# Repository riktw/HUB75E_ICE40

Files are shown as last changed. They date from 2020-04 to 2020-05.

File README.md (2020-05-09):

# HUB75E_ICE40
SpinalHDL code to drive a 64*64 pixel HUB75E module with an ICE40

This code is used to drive a HUB75E dislay, fast enough to display animated gifs:


This project uses SpinalHDL, see installation notes here: https://spinalhdl.github.io/SpinalDoc-RTD/SpinalHDL/Getting%20Started/index.html

To build, yosys and nextpnr are used, see installation notes here: http://www.clifford.at/icestorm/

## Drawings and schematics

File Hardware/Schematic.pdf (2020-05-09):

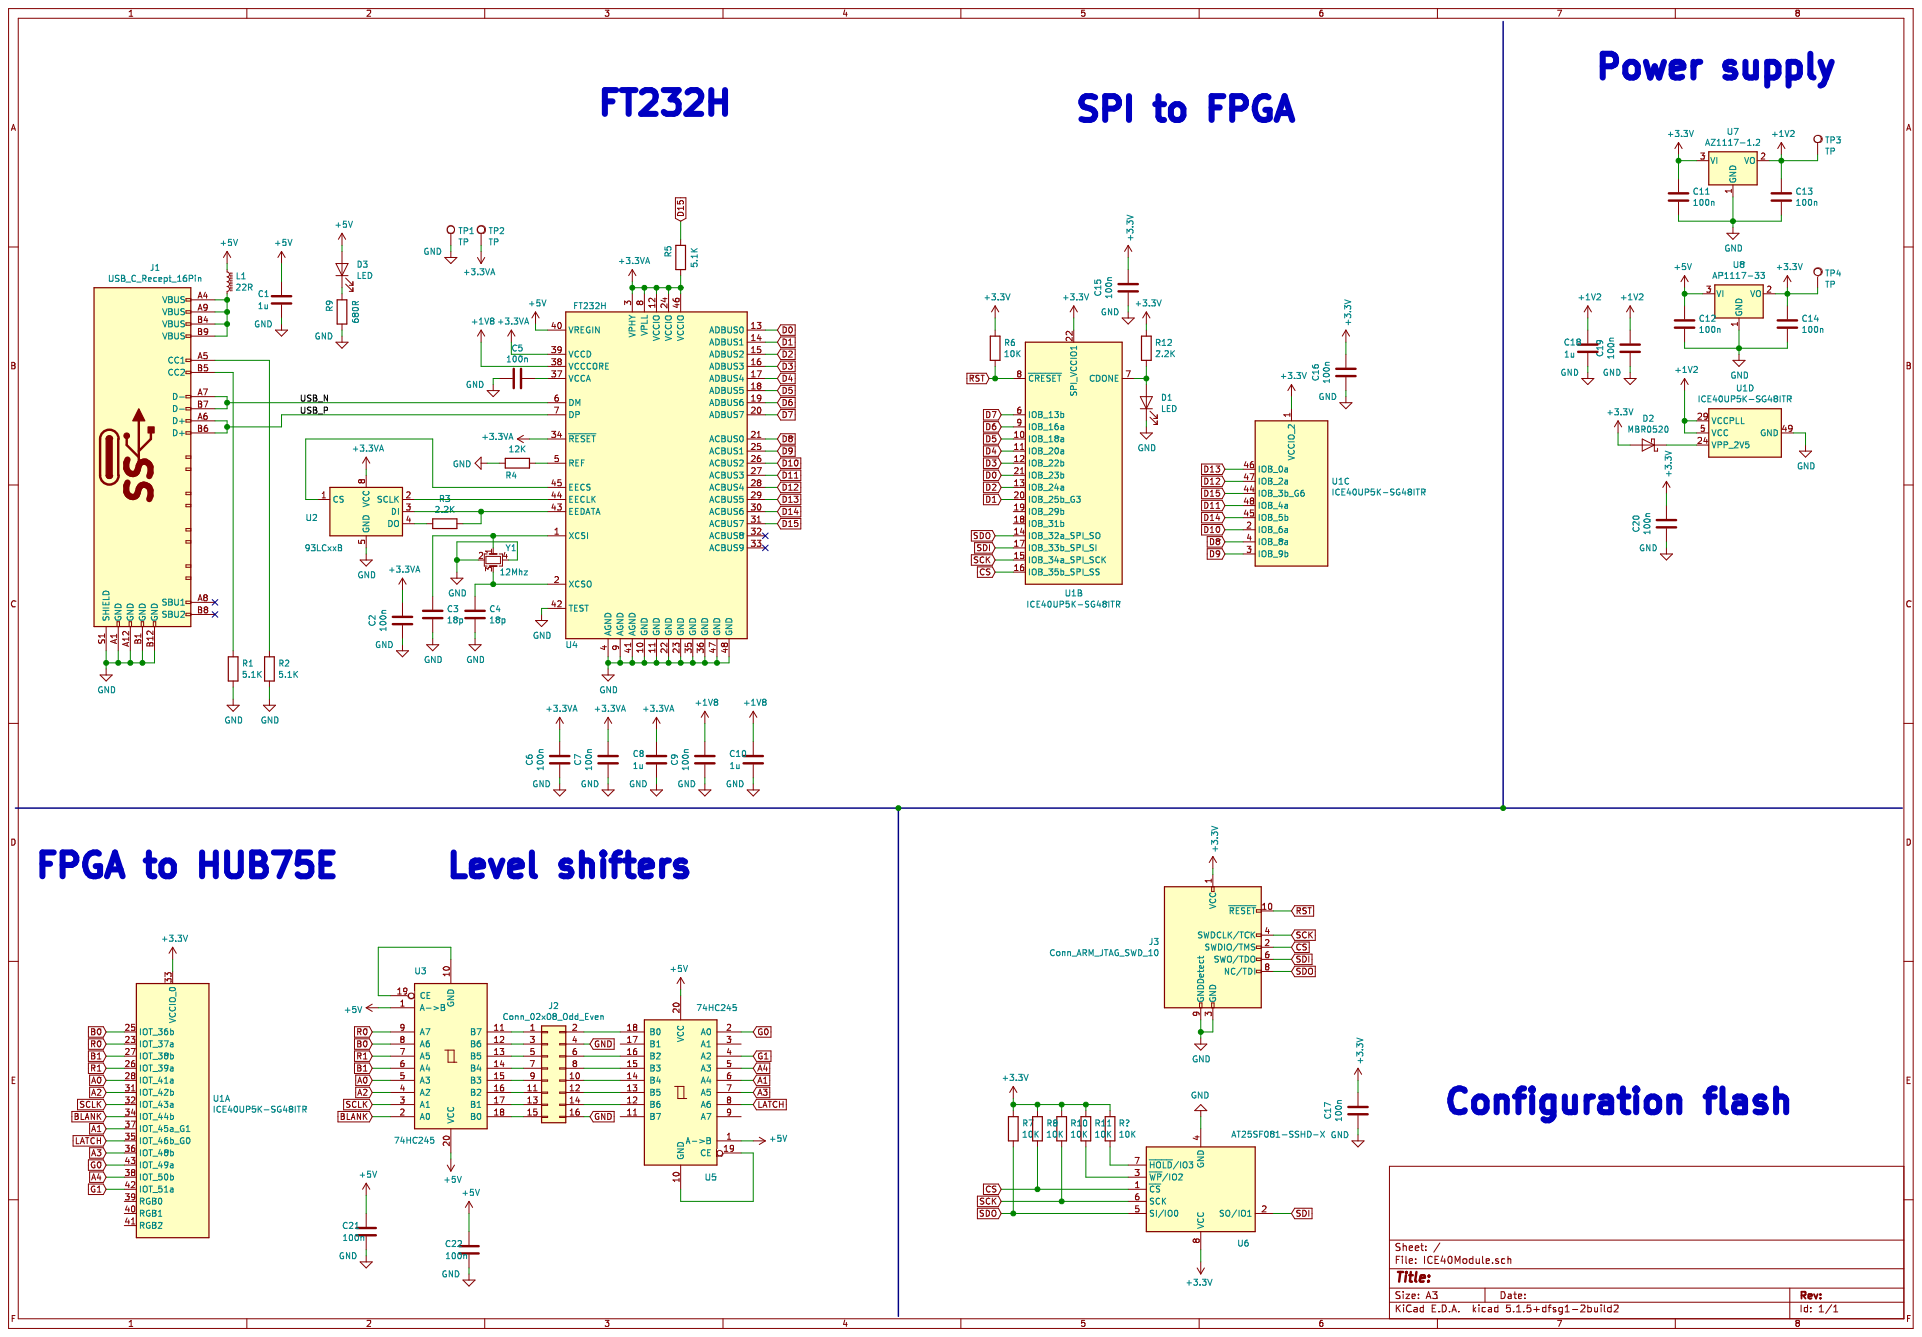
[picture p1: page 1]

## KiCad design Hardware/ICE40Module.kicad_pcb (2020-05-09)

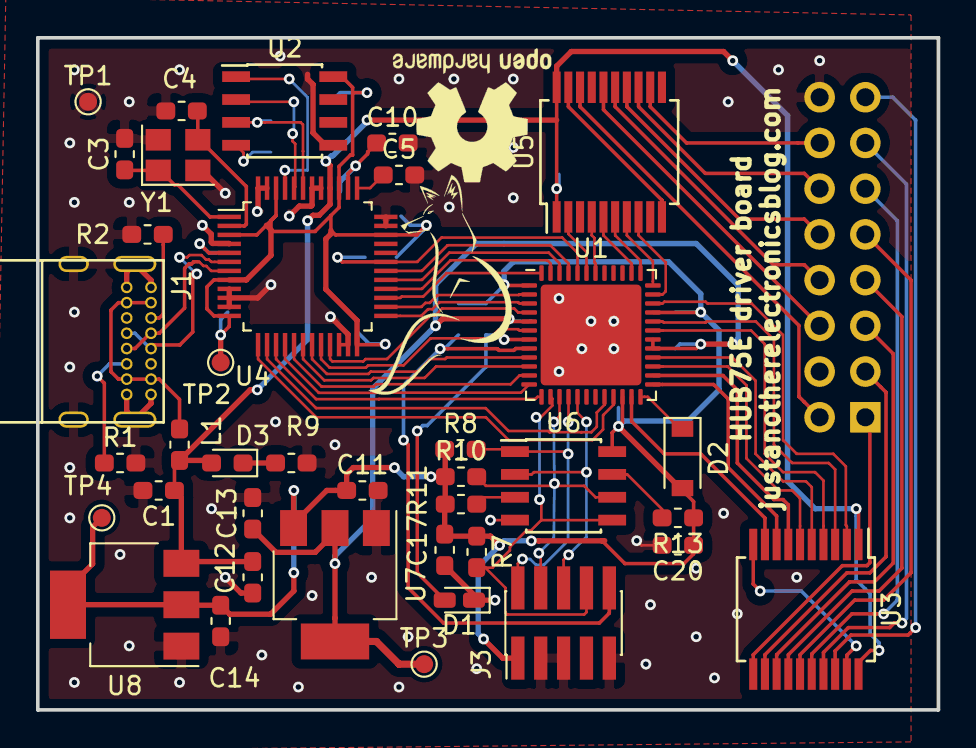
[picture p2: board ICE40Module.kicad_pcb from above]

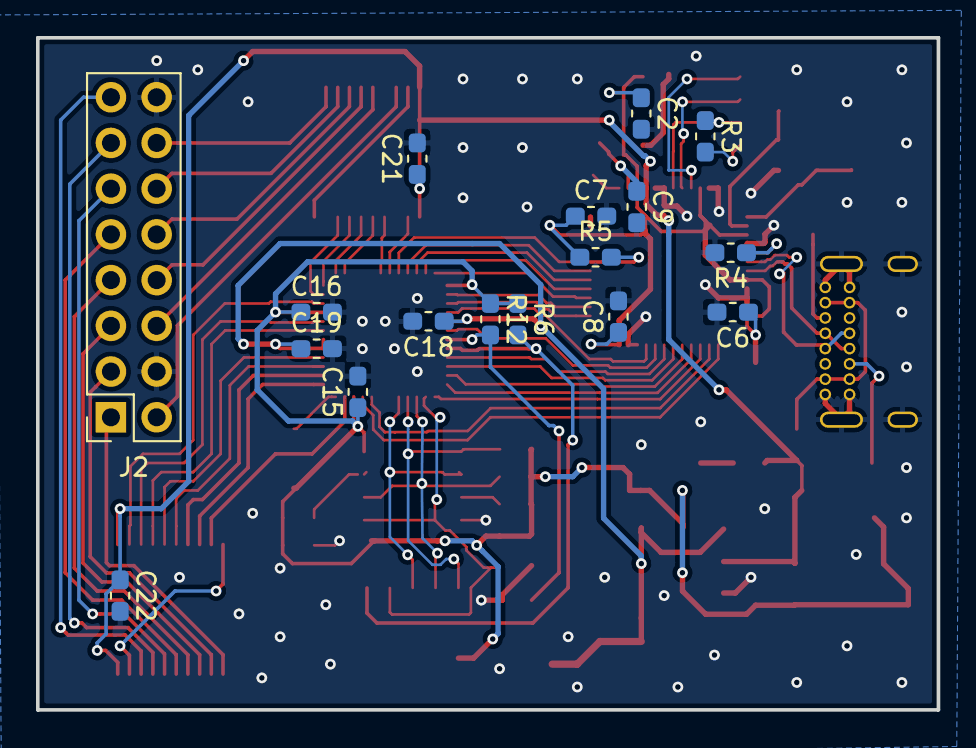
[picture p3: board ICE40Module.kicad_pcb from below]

Board: 2 copper layers, 50.0 x 37.3 mm, 55 parts (17 on the bottom side), 75 nets.

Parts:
C1, C8, C10, C18: 1u; C_0603_1608Metric_Pad1.05x0.95mm_HandSolder
C2, C5, C6, C7, C9, C11, C12, C13, C14, C15, C16, C17, C19, C20, C21, C22: 100n; C_0603_1608Metric_Pad1.05x0.95mm_HandSolder
C3, C4: 18p; C_0603_1608Metric_Pad1.05x0.95mm_HandSolder
D1: LED; LED_0603_1608Metric_Castellated
D2: MBR0520; D_SOD-123
D3: LED; LED_0603_1608Metric_Pad1.05x0.95mm_HandSolder
J1: USB_C_Recept_16Pin
J2: Conn_02x08_Odd_Even; PinSocket_2x08_P2.54mm_Vertical
J3: Conn_ARM_JTAG_SWD_10; PinHeader_2x05_P1.27mm_Vertical_SMD
L1: 22R; L_0603_1608Metric_Pad1.05x0.95mm_HandSolder
R1, R2, R5: 5.1K; R_0603_1608Metric_Pad1.05x0.95mm_HandSolder
R3, R12: 2.2K; R_0603_1608Metric_Pad1.05x0.95mm_HandSolder
R4: 12K; R_0603_1608Metric_Pad1.05x0.95mm_HandSolder
R6, R7, R8, R10, R11, R13: 10K; R_0603_1608Metric_Pad1.05x0.95mm_HandSolder
R9: 680R; R_0603_1608Metric_Pad1.05x0.95mm_HandSolder
TP1, TP2, TP3, TP4: TP; TestPoint_Pad_D1.0mm
U1: ICE40UP5K-SG48ITR; QFN-48-1EP_7x7mm_P0.5mm_EP5.6x5.6mm
U2: 93LCxxB; SOIC-8_3.9x4.9mm_P1.27mm
U3, U5: 74HC245; SSOP-20_5.3x7.2mm_P0.65mm
U4: FT232H; LQFP-48_7x7mm_P0.5mm
U6: AT25SF081-SSHD-X; SOIC-8_3.9x4.9mm_P1.27mm
U7: AZ1117-1.2; SOT-223-3_TabPin2
U8: AP1117-33; SOT-223-3_TabPin2
Y1: 12Mhz; Crystal_SMD_3225-4Pin_3.2x2.5mm

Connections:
+1V2: C13.1, C18.1, C19.1, TP3.1, U1.5, U1.29, U1.30, U7.2
+1V8: C9.1, C10.1, U4.38
+3.3VA: C2.1, C6.1, C7.1, C8.1, R5.1, TP2.1, U2.8, U4.3, U4.8, U4.12, U4.24, U4.34, U4.39, U4.46
+3V3: C11.1, C14.1, C15.1, C16.1, C17.1, C20.1, D2.2, J3.1, R6.1, R7.1, R8.1, R10.1, R11.1, R12.1, R13.1, TP4.1, U1.1, U1.22, U1.33, U6.8, U7.3, U8.2
+5V: C1.1, C12.1, C21.1, C22.1, D3.2, L1.1, U3.1, U3.20, U4.40, U5.1, U5.20, U8.3
/USB_N: J1.A7, J1.B7, U4.6
/USB_P: J1.A6, J1.B6, U4.7
A0: U1.28, U3.5
A1: U1.37, U5.6
A2: U1.31, U3.4
A3: U1.36, U5.7
A4: U1.38, U5.5
B0: U1.25, U3.8
B1: U1.27, U3.6
BLANK: U1.34, U3.2
CS: J3.2, R8.2, U1.16, U6.1
D0: U1.21, U4.13
D1: U1.20, U4.14
D2: U1.13, U4.15
D3: U1.12, U4.16
D4: U1.11, U4.17
D5: U1.10, U4.18
D6: U1.9, U4.19
D7: U1.6, U4.20
D8: U1.4, U4.21
D9: U1.3, U4.25
D10: U1.2, U4.26
D11: U1.48, U4.27
D12: U1.47, U4.28
D13: U1.46, U4.29
D14: U1.45, U4.30
D15: R5.2, U1.44, U4.31
G0: U1.43, U5.2
G1: U1.42, U5.4
GND: C1.2, C2.2, C3.2, C4.2, C5.2, C6.2, C7.2, C8.2, C9.2, C10.2, C11.2, C12.2, C13.2, C14.2, C15.2, C16.2, C17.2, C18.2, C19.2, C20.2, C21.2, C22.2, D1.1, J1.A1, J1.A12, J1.B1, J1.B12, J1.S1, J2.4, J2.16, J3.3, J3.5, J3.9, R1.2, R2.2, R4.2, R9.1, TP1.1, U1.49, U2.5, U4.4, U4.9, U4.10, U4.11, U4.22, U4.23, U4.35, U4.36, U4.41, U4.42, U4.47, U4.48, U6.4, U7.1, U8.1, Y1.2, Y1.4
LATCH: U1.35, U5.8
unnamed: C3.1, U4.1, Y1.1
unnamed: C4.1, U4.2, Y1.3
unnamed: C5.1, U4.37
unnamed: D1.2, R12.2, U1.7
unnamed: D2.1, U1.24
unnamed: D3.1, R9.2
unnamed: J1.A4, J1.A9, J1.B4, J1.B9, L1.2
unnamed: J1.A5, R2.1
unnamed: J1.B5, R1.1
unnamed: J2.1, U3.11
unnamed: J2.2, U5.18
unnamed: J2.3, U3.12
unnamed: J2.5, U3.13
unnamed: J2.6, U5.16
unnamed: J2.7, U3.14
unnamed: J2.8, U5.15
unnamed: J2.9, U3.15
unnamed: J2.10, U5.14
unnamed: J2.11, U3.16
unnamed: J2.12, U5.13
unnamed: J2.13, U3.17
unnamed: J2.14, U5.12
unnamed: J2.15, U3.18
unnamed: R3.1, U2.3, U4.43
unnamed: R3.2, U2.4
unnamed: R4.1, U4.5
unnamed: R11.2, U6.3
unnamed: R13.2, U6.7
unnamed: U2.1, U4.45
unnamed: U2.2, U4.44
unnamed: U3.10, U3.19
unnamed: U5.10, U5.19
R0: U1.23, U3.9
R1: U1.26, U3.7
RST: J3.10, R6.2, U1.8
SCK: J3.4, R10.2, U1.15, U6.6
SCLK: U1.32, U3.3
SDI: J3.6, U1.17, U6.2
SDO: J3.8, R7.2, U1.14, U6.5

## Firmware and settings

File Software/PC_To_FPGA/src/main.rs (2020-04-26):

#[macro_use]
extern crate bmp;
use bmp::{Pixel, Image};
use std::{thread, time};
use clap::{Arg, App};
use std::fs::File;
use gif::SetParameter;
use std::sync::Arc;
use std::sync::atomic::{AtomicBool, Ordering};
extern crate ftdi_embedded_hal as hal;

extern crate embedded_hal;
use embedded_hal::blocking::spi::Transfer;

use crate::hal::x232h::FTx232H;

fn get_bit_at(input: u8, n: u8) -> bool {
    if n < 8 {
        input & (1 << n) != 0
    } else {
        false
    }
}

fn show_bmp(img: &mut Image, spidev: &mut hal::spi::SpiBus, brightness: u32)
{
    let mut image_in_rows: [[u8; 3*64] ; 64] = [[0; 3*64] ; 64];
    let mut row_total: [[u64; 64] ; 24] = [[0; 64] ; 24];
    
    for (x, y) in img.coordinates() {
        let mut pixel_temp: Pixel = img.get_pixel(x, y);
        pixel_temp.r = ((pixel_temp.r as f64 / 255.0).powf(1.5) * 255.0) as u8;
        pixel_temp.g = ((pixel_temp.g as f64 / 255.0).powf(1.5) * 255.0) as u8;
        pixel_temp.b = ((pixel_temp.b as f64 / 255.0).powf(1.5) * 255.0) as u8;
        img.set_pixel(x, y, pixel_temp);
    }
    
    // turn the image from a 64*64 array of RGB pixels to an array of 64 * 192 of u8's 
    // containing a row of red, then green, then blue, then red and so on u8's
    for (x, y) in img.coordinates() {
        let pixel_temp: Pixel = img.get_pixel(x, y);
        image_in_rows[y as usize][(x*3) as usize] = pixel_temp.r;
        image_in_rows[y as usize][((x*3)+1) as usize] = pixel_temp.g;
        image_in_rows[y as usize][((x*3)+2) as usize] = pixel_temp.b;
        
        
        //The display has 8 bit colour per pixel, memory is stored as 64 bit red MSB, 64 bit red msb-1, 64 bit red msb-2 and so on.
        //then green, then blue. So 24 64bit words per row of 64 LEDs. 
        //This code turns the array with u8's per colour into the above.
        for n in 0..8 {
            if get_bit_at(image_in_rows[y as usize][ (x*3) as usize], n)
            {
                row_total[(n) as usize][y as usize] += 1 << x;
            }
            if get_bit_at(image_in_rows[y as usize][ ((x*3)+1) as usize], n)
            {
                row_total[(8+n) as usize][y as usize] += 1 << x;
            }
            if get_bit_at(image_in_rows[y as usize][ ((x*3)+2) as usize], n)
            {
                row_total[(16+n) as usize][y as usize] += 1 << x;
            }
        }
    }
    
    let value_brightness = brightness;
    
    let mut data_to_send: [u8; 8] = [0; 8];
    
    let mut chunk_to_send: [u8; 2*24*8] = [0; 2*24*8];
    let mut address:u16 = 0x4000;
    
    //split 64 bit words into 2 * 32 bit, wrap around the wishbone protocol (0x01, 0x01, address, value) and send over.
    for y in 0..64 {
        
        for n in 0..24 {
            let value_low:u32 = (row_total[n as usize][y as usize] >> 32) as u32;
            let value_high:u32 = row_total[n as usize][y as usize] as u32;
            
            let address_bytes = address.to_be_bytes();
            let value_bytes = value_low.to_be_bytes();
            
            chunk_to_send[(n*16)+0] = 1;
            chunk_to_send[(n*16)+1] = 1;
            
            for x in 0..2 {
                chunk_to_send[(n*16)+(2+x) as usize] = address_bytes[x];
            }
            
            for x in 0..4 {
                chunk_to_send[(n*16)+(4+x) as usize] = value_bytes[x];
            }
            address = address + 1;
            
            let address_bytes = address.to_be_bytes();
            let value_bytes = value_high.to_be_bytes();
            
            chunk_to_send[((n*16)+8)+0] = 1;
            chunk_to_send[((n*16)+8)+1] = 1;
    
            for x in 0..2 {
                chunk_to_send[((n*16)+8)+(2+x) as usize] = address_bytes[x];
            }
            
            for x in 0..4 {
                chunk_to_send[((n*16)+8)+(4+x) as usize] = value_bytes[x];
            }
            
            address = address + 1;
        }
        spidev.transfer(&mut chunk_to_send).unwrap();
    }
    
    address = 0;
    let address_bytes = address.to_be_bytes();
    let value_bytes = value_brightness.to_be_bytes();
    
    data_to_send[0] = 1;
    data_to_send[1] = 1;
    
    for n in 0..2 {
        data_to_send[(2+n) as usize] = address_bytes[n];
    }
    
    for n in 0..4 {
        data_to_send[(4+n) as usize] = value_bytes[n];
    }
    spidev.transfer(&mut data_to_send).unwrap();
    
    address = 4;
    let address_bytes = address.to_be_bytes();
    let value_memory:u32 = 1;
    let value_bytes = value_memory.to_be_bytes();
    
    data_to_send[0] = 1;
    data_to_send[1] = 1;
    
    for n in 0..2 {
        data_to_send[(2+n) as usize] = address_bytes[n];
    }
    
    for n in 0..4 {
        data_to_send[(4+n) as usize] = value_bytes[n];
    }
    spidev.transfer(&mut data_to_send).unwrap();
}

fn main() {

	let matches = App::new("image loader")
       .version("0.1")
       .about("Loads an image to rgb matrix")
       .author("Rik")
		.arg(
			Arg::with_name("Image file location")
			.help("Location of the image file to transmit")
			.takes_value(true)
			.short("f")
            .long("file")
			.required(true),
        )
        .arg(
			Arg::with_name("Brightness")
			.help("Brightness of the panel")
			.takes_value(true)
			.short("b")
            .long("brightness")
			.required(true),
        )
        .arg(
			Arg::with_name("Loop")
			.help("1 if a gif should loop forever")
			.takes_value(true)
			.short("l")
            .long("loop")
			.required(false),
        )
       .get_matches(); 
    
    let dev = FTx232H::init(0x0403, 0x6015).unwrap();  //Normally 0403 6014 but that already is my FPGA programmer :)
    let mut spidev = dev.spi(hal::spi::SpiSpeed::CLK_10MHz).unwrap();
    
    let shutdownApplication = Arc::new(AtomicBool::new(false));
    let sharedShutdownApplication = Arc::clone(&shutdownApplication);
    ctrlc::set_handler(move || {
        sharedShutdownApplication.swap(true, Ordering::Relaxed);
    })
    .expect("Error setting Ctrl-C handler");
    
    let mut value_brightness:u32;
    let brightness = matches.value_of("Brightness").unwrap();	
    if let Ok(brigh) = brightness.parse::<u32>() {
        value_brightness = brigh.into();
    } else {
        eprintln!("Error: Invalid brightness '{}' specified", brightness);
        ::std::process::exit(1);
    }
    
    let filename = matches.value_of("Image file location").unwrap();
    println!("file name: {}", filename);
    let tokens:Vec<&str>= filename.split(".").collect();
    if(tokens[1] == "bmp") {
        let mut img = bmp::open(filename).unwrap_or_else(|e| {
            panic!("Failed to open: {}", e);
        });
        
        show_bmp(&mut img.clone(), &mut spidev, value_brightness);

    }
    else if(tokens[1] == "gif") {
        
        let mut loopval:u32 = 0;
        if let Some(o) = matches.value_of("Loop") {
            if let Ok(loopint) = o.parse::<u32>() {
                loopval = loopint.into();
            } else {
                eprintln!("Error: Invalid loop '{}' specified", o);
                ::std::process::exit(1);
            }
        }
        
        loop{
        
            let mut decoder = gif::Decoder::new(File::open(filename).unwrap());
            decoder.set(gif::ColorOutput::RGBA);
            let mut decoder = decoder.read_info().unwrap();
            
            let mut imggif = Image::new(64, 64);
            
            let mut cnt = 0;
            
            
            while let Some(frame) = decoder.read_next_frame().unwrap() {
                if(frame.delay >= 4){
                    thread::sleep(time::Duration::from_millis((10*(frame.delay-3)).into()));
                }
                        
                for y in 0..frame.width {
                    for x in 0..frame.height {
                        let mult = frame.width*4;
                        if(frame.buffer[3+((y*4)+(x*mult)) as usize] == 255) {
                            imggif.set_pixel((frame.left + y).into(), (frame.top + x).into(), px!(frame.buffer[0+((y*4)+(x*mult)) as usize], frame.buffer[1+((y*4)+(x*mult)) as usize], frame.buffer[2+((y*4)+(x*mult)) as usize]));
                        }
                    }
                }
                
                show_bmp(&mut imggif.clone(), &mut spidev, value_brightness);
                
                if(shutdownApplication.load(Ordering::Relaxed) == true){
                    loopval = 0;
                    break;
                }
                    
            }
            
            if(loopval != 1){break;}
        }
        
    }
    println!("Done!");
 
}

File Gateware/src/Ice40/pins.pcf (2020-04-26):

set_io io_clk  4
set_io io_RGB0_R 23
set_io io_RGB0_G 25
set_io io_RGB0_B 43
set_io io_RGB1_R 26
set_io io_RGB1_G 27
set_io io_RGB1_B 42
set_io io_Latch 35
set_io io_Blank 34
set_io io_sclk 32 
set_io io_Address[0] 28
set_io io_Address[1] 37
set_io io_Address[2] 31
set_io io_Address[3] 36
set_io io_Address[4] 38

set_io io_spi_sclk 21
set_io io_spi_mosi 20
set_io io_spi_miso_write 19
set_io io_spi_miso_writeEnable 18
set_io io_spi_ss 11
